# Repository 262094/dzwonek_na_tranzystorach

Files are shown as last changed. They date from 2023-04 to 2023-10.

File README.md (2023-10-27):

# dzwonek_na_tranzystorach
jest to aplikacja dzwonka z lat '80 typu słowik ze standardowego montażu przewlekanego THT, dzwonek został zaadaptowany na obecnie panujący trend miniaturyzacji elektroniki w połączeniu głownie montażu SMD z niektórymi elementami THT (tranzystor PNP BD140, brzęczyk bez generatora, kondensatory elektrolityczne 470uF, przycisk, złącze ARK500/2, potencjometr i kondensator ceramiczny 33nF), dzwonek udało się umieścić w wymiarach 66x37,5 (mm). W dzwonku występuje generator częstotliwości dla dzwonka złożony z przerzerzutnika Schmitta połączonego z układem Sziklaiego (wzmocnienie parametru B na wyjściu układu dla brzęczyka) oraz z przerzutnika monostabilnego jako modulatora generowanego tonu z poprzedniego przerzutnika. Układ może pracować w zasilaniu 9V DC jak i 230V AC po uprzednim zaadoptowaniu. Projekt został przygotowany do samodzielnego wytrawienia na laminacie pokrytym warstwą miedzi.

*** WIECEJ MOICH PROJEKTOW JEST DOSTEPNYCH NA MOIM KONCIE ZAPRASZAM DO ZAPOZANANIA SIE Z NIMI APLIKACJA HEALTH_CHECK ORAZ FINANCIFY***

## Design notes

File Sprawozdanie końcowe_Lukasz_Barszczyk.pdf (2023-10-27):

## Sprawozdanie końcowe

## Laboratorium Otwarte

## Dzwonek do drzwi typu słowik

Łukasz Barszczyk

Nr indeksu: 262094

Spis treści

### 1. Wstęp

Projekt obejmuje wykonanie dzwonka do drzwi typu słowik wykorzystując dwa

przerzutniki astabilne do generowania i modulowania tonu oraz wzmacniacz głośnikowy

w postaci dwóch tranzystorów (jeden NPN, drugi PNP) w układzie Sziklaiego

(układ wzmacniacza opartego | na | tranzystorach | bipolarnych o | dużym | wzmocnieniu,

rodzaj układu Darlingtona, w którym zastosowane są tranzystory o przeciwstawnej

(komplementarnej) polaryzacji). W celu dostosowania częstotliwości dźwięku do swoich

potrzeb mamy możliwość jej regulacji za pomocą potencjometru umieszczonego w układzie.

Typowe zastosowanie układu to dołączenie do urządzenia zasilania bateryjnego (np. baterii

9V) lub na co pozwala układ transformatora dzwonkowego. W drugim przypadku należy

pamiętać, że w takim systemie występuje napięcie sieci 230V i należy zachować szczególną

ostrożność.

Ideę działania układu zaczerpnięto z książki „Dla domu: 24 proste układy elektroniczne do

samodzielnego wykonania” autorstwa Marii i Wojciecha Nowakowskich. Na podstawie

zmodyfikowanego układu wykonano symulację w programie LTspice.

Ze względu na trudności w znalezieniu źródeł literaturowych opisujących działanie obwodu

zbliżonego do analizowanego, podstawowym źródłem wiedzy na temat sposobu działania było

badanie układu przez jego symulacje, pobudzanie zmianami parametrów oraz budowę układu

na płytce obwodu drukowanego i jego pomiary za pomocą oscyloskopu. Pomimo wielu różnic,

względem oryginalnego dzwonka, pomocne w zrozumieniu układu okazały się informacje

zamieszczone w Internecie na temat multiwibratorów.

### 2. Schemat układu i sposób działania

Na rys. 1. przedstawiono schemat ideowy układu.

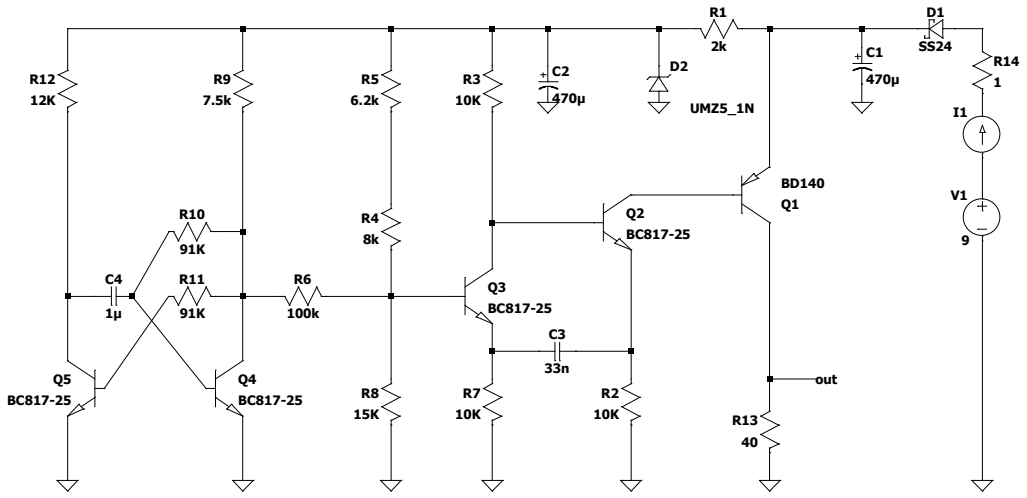
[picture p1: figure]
UMZ5_1N 470µ; out

Prezentowany układ jest współczesną wersją układu dzwonka do drzwi o przyjemnym

brzmieniu, którego pierwowzór został zbudowany z elementów przewlekanych w latach 80. ubiegłego wieku. Ówcześnie zbudowany był z elementów przewlekanych, które obecnie

zostały zastąpione elementami elektronicznymi wykonanymi w technologii montażu

powierzchniowego SMD. Dzięki temu urządzenie jest mniejsze, tańsze oraz łatwiejsze

w montażu.

Sposób działania układu polega na pracy tranzystorów Q2 oraz Q3, które tworzą

przerzutnik astabilny pracujący jako generator tonu. Częstotliwość generowanego tonu

możemy regulować za pomocą potencjometru (w symulacji LTspice potencjometr został

zastąpiony rezystorem). Tranzystory bipolarne Q4 oraz Q5 także pracują w konfiguracji

przerzutnika astabilnego. Zadaniem tego przerzutnika jest modulacja wysokości tonu

generowanego przez układ zbudowany z tranzystorów Q2 i Q3. Funkcję głośnikowego

wzmacniacza mocy pełni zewnętrzny tranzystor bipolarny Q1 – BD140.

Rys. 1. Schemat układu dzwonka

W symulacji na wejściu układu znajduję się źródło napięciowe sterowane prądem. Ten

element układu jest odpowiedzialny za symulowanie wciskania przycisku przez użytkownika

dzwonka, w celu odzwierciedlenia rzeczywistego obwodu (w schemacie właściwym, element ten został zastąpiony przyciskiem). Źródło napięciowe jest zależne od źródła prądowego

Tranzystory Q4 i Q5 tworzą multiwibrator dwustanowy monostabilny – układ jest

symetryczny lewa i prawa strona są bardzo podobne. Zakładamy, że po włączeniu napięcia

jeden z tranzystorów zostanie włączony, czyli na jego bazie pojawi się napięcie ok 0.7 V.

W teorii układ może pozostać w równowadze, jeżeli wartości jego elementów byłyby idealne

(takie same). W praktyce jednak tak nie jest więc układ przeskoczy do jednego ze skrajnych

stanów. Tranzystor Q5 w tym przypadku przewodzi, a Q4 jest zatkany, ponieważ występuje

ujemne napięcie w punkcie pomiędzy C4 a Q4. Ujemne napięcie bierze się stąd, że lewa

okładka kondensatora została zwarta do masy poprzez złącze C-E tranzystora Q5, była

na potencjale dodatnim, a prawa strona kondensatora na potencjale masy, jeśli kondensator

rozładował się poprzez Q5 to w punkcie pomiędzy C4 a Q4 wystąpiło napięcie ujemne,

ponieważ potencjał kondensatora obniżył się. Z tego względu Q4 jest zatkany. Jednak potencjał

cały czas rośnie, ponieważ kondensator coraz bardziej się rozładowuje. Kiedy napięcie bazy

tranzystora Q4 osiągnie ok. 0,7V to tranzystor Q4 się otworzy spowoduje to spadek napięcia

na bazie Q5 i jego zatkanie. Po naładowaniu się kondensatora C4, układ jest gotowy do

następnego wyzwolenia. Zadaniem tego przerzutnika jest modulacja wysokości tonu

generowanego przez układ zbudowany z tranzystorów Q2 i Q3.

Tranzystory Q2 i Q3 pracują w układzie przerzutnika Schmitta. Układem Schmitta

nazywamy układ, w którym oba stopnie są połączone gałęzie, w której występuje sumowanie

sygnałów pochodzących z obu stopni. Przerzutnik Schmitta ma w obwodzie wejściowym dwa

progi przełączania, przy których wyjście zmienia stan na przeciwny. Osiągnięcie przez napięcie

wejściowe określonego progu zależy od kierunku zmiany tego napięcia. Dla napięcia

narastającego obowiązuje próg górny, dla opadającego - dolny. Odległość między progami

określa się mianem szerokości pętli histerezy. Po przekroczeniu pewnego progu przerzutnik

przerzuca się na stan wysoki na wyjściu. Jeśli napięcie spadnie poniżej tego progu na wyjściu

układu pojawi się stan niski. Wpływ na stan niski w układzie wywiera umieszczony

kondensator emiterowy, który przemiennie ładuję się i rozładowuje. Na wyjściu układu

znajduję się tranzystor PNP (Q1), umożliwia on lepszą oscylację sygnału pomiędzy stanem

niskim, a wysokim, ponieważ do jego otwarcia na bazie wymagane jest napięcie o około 0,6V

niższe od napięcia kolektora, a dodatkowo wzmacnia sygnał. Jest to najprostszy generator

częstotliwości. Sprężenie zwrotne ujemne stabilizuje punkt pracy, a ponadto może nie dopuszczać do wystąpienia przesterowania w układzie. Układ pracuje wówczas bez

wchodzenia w obszar nasycenia, dzięki czemu uzyskuje się przebiegi o stromych zboczach

z małym opóźnieniem czasowym (zwanym histerezą) względem impulsów wyzwalających.

Układy Schmitta stosuje się jako przerzutniki monostabilne lub bistabilne oraz do formowania

przebiegów prostokątnych. Zaletą układu jest m.in to, że wejście układu nie jest objęte pętla

sprężenia zwrotnego i dzięki temu na wejściu nie istnieją sygnały wytworzone wewnątrz

układu, jak to występuje w układzie Ecclesa-Jordana. Ponadto wyjście układu jest dobrze

odseparowane od wejścia. W tym układzie sygnał wejściowy jest podawany na bazę

pierwszego tranzystora, a wyjście odczytuje się z kolektora drugiego tranzystora. W stanie

początkowym, kiedy sygnał wejściowy jest na poziomie niskim, oba tranzystory są wyłączone,

kondensator jest rozładowany poprzez oporniki bazy i kolektora.

Gdy sygnał wejściowy przekracza poziom progowy, napięcie na bazie pierwszego tranzystora

zaczyna rosnąć, co powoduje, że ten tranzystor zaczyna przewodzić. Wskutek tego kondensator

zaczyna się ładować poprzez tranzystor pierwszy i opornik bazy tranzystora drugiego. Gdy

napięcie na emiterze pierwszego tranzystora osiągnie poziom progowy, napięcie na bazie

drugiego tranzystora zaczyna rosnąć, co powoduje, że ten tranzystor także zaczyna przewodzić.

Teraz kondensator zaczyna się rozładowywać. Gdy napięcie na emiterze drugiego tranzystora

spadnie poniżej poziomu progowego, tranzystor ten przestaje przewodzić, a kondensator

zaczyna się ponownie ładować poprzez drugi tranzystor. W ten sposób przerzutnik Schmitta

z dwóch tranzystorów NPN ze wspólnym kondensatorem emiterowym umożliwia zmianę stanu

sygnału wejściowego między stanem niskim a wysokim w sposób stabilny i jednoznaczny,

niezależnie od szumów i zakłóceń w sygnale generując sygnał wyjściowy.

Tranzystory Q1 i Q2 pracują jako układ Sziklaiego układ wzmacniacza oparty

na tranzystorach bipolarnych o dużym wzmocnieniu, rodzaj układu Darlingtona, w którym

zastosowane są tranzystory o przeciwstawnej (komplementarnej) polaryzacji, tzn. np. pierwszy

z nich (na rysunku oznaczony Q2) jest n-p-n, a drugi p-n-p. Emiter pierwszego tranzystora

połączony jest z kolektorem drugiego, natomiast kolektor pierwszego tranzystora steruje wprost

bazą drugiego. Całość w układzie jak na rysunku obok zachowuje się jak pojedynczy tranzystor

n-p-n o dużym wzmocnieniu. Wynikowy tranzystor Sziklaiego swój kolektor ma tam, gdzie

jest emiter tranzystora Q1.

Układ prostownika z diodą (D1) i kondensatorem(C1) pozwala na zmianę napięcia

przemiennego na stałe napięcie pulsujące (zasilanie 230V). W przypadku zasilania z baterii 9V,

może to pomóc w uzyskaniu wyższych wartości napięcia, co jest przydatne w niektórych

układach elektronicznych. Jednakże, należy pamiętać, że napięcie wyjściowe takiego prostownika jest pulsujące i nie jest idealnie stabilne. Zastosowanie stabilizatora napięcia może

być konieczne, aby uzyskać stałe napięcie wyjściowe.

Układ stabilizatora (R1, D2, C2) pozwala na utrzymanie stałego napięcia wyjściowego

bez względu na zmiany napięcia zasilania i obciążenia. W przypadku braku stabilizatora,

napięcie wyjściowe będzie zmieniać się w zależności od stanu naładowania baterii, co może

wpłynąć na działanie urządzenia, które jest zasilane tymi bateriami. Zastosowanie stabilizatora

pozwala na uzyskanie stabilnego napięcia wyjściowego, co zwiększa nie tylko niezawodność

i trwałość urządzenia, ale także może pomóc w poprawie jakości działania

### 2.1 Modyfikacje schematu

Schemat z rysunku 1. po wstępnym przetestowaniu działa poprawnie i zgodnie

z założeniami postawionymi we wstępie. Jednak w celu wyeliminowania konieczności

zamawiania nowych elementów dokonano zamiany diody Zenera UMZ5_1N na diodę

o zbliżonych parametrach do tej BZV55C5V6. Zmiana ta nie wpływa znacząco na działanie

układu, gdzie jest dalej zachowane ustabilizowane napięcie, które nie spowoduje uszkodzenia

tranzystora Q4 napięciem wstecznym E-B (deklarowana wartość przez producenta

maksymalnego napięcia wstecznego 5V).

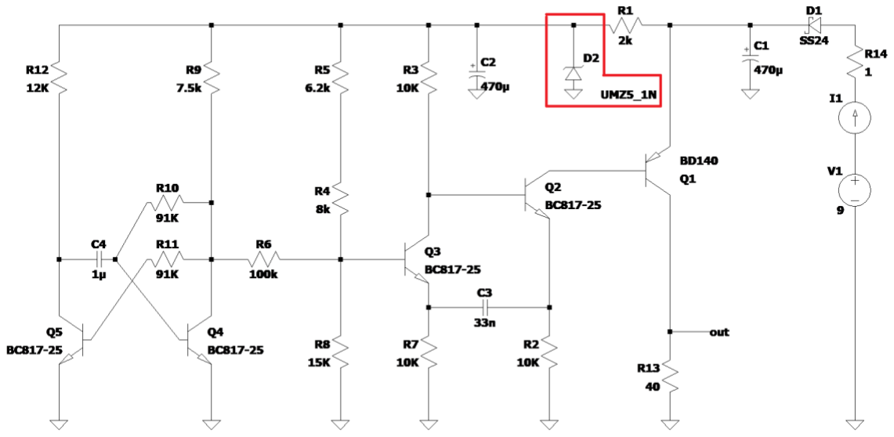
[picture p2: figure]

Rys. 2. Układ z zaznaczonym elementem, który wymieniono

### 3. Symulacja układu w programie LTspice

Ze względu na braki niektórych z elementów w LTspice, na których planowano wykonanie

układu przyjęto pewne uproszczenia w symulacji: zamiast diody Zenera BZV55C5V6

zastosowane w symulacji diodę UMZ5_1N oraz zamiast przycisku zastosowano źródło

napięciowe sterowane źródłem prądowym imitując tym pracę przycisku. Dla możliwości

usłyszenia dźwięku dzwonka w symulacji, zastosowano formułę „wave”, która generuje plik

dźwiękowy z programu według uzyskanych parametrów na wyjściu „out”. Przed wyjściem

układu umieszczono także rezystor o wartości 40 Ohm, służący za przybliżenie oporu

brzęczyka na wyjściu.

Rys. 3. Schemat ideowy układu w programie LTspice

W trakcie symulacji poddano analizie następujące parametry:

- Napięcie baza-emiter tranzystora Q2, Q3, Q4 oraz Q5
- Napięcie kolektora tranzystora Q4 oraz Q5
- Napięcia emitera tranzystora Q3 oraz Q2
- Napięcie uzyskane na wyjściu układu
- Napięcie uzyskane po wyprostowaniu przez prostownik

Biorąc pod uwagę właściwości aplikacyjne układu, za najważniejsze zostały uznane

napięcia uzyskane podczas pracy obu przerzutników. Szczegółowa analiza dokonywana jest

dla napięcia bateryjnego 9V – założono, że takie napięcie będzie najczęściej wykorzystywane.

### 3.1 Wykresy związane z pracą tranzystorów Q4 i Q5

Rysunki 4., 5., 6. i 7. ukazują przebiegi zgodne z oczekiwanymi. Podczas krótkich

impulsów włączających naprzemiennie tranzystory Q4 i Q5. Pracując w konfiguracji

przerzutnika astabilnego modulują wysokości tonu generowanego przez układ zbudowany

z tranzystorów Q2 i Q3.

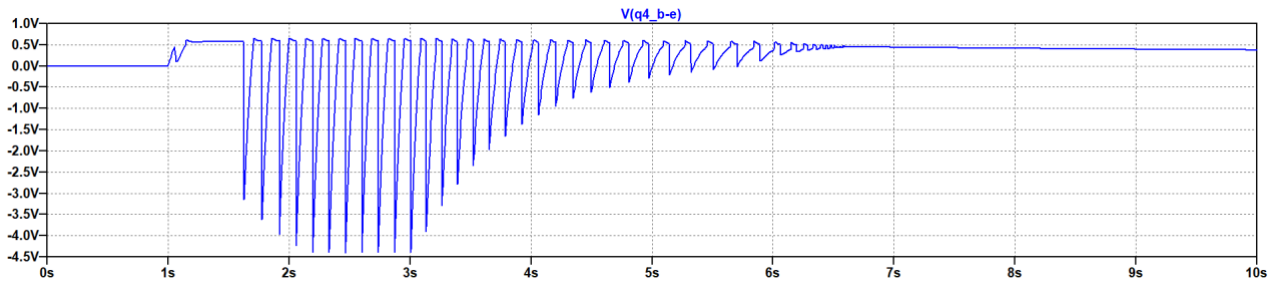
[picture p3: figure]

Rys. 4. Przebieg napięcia baza-emiter tranzystora Q4

Jak widać na rysunku powyżej (Rys. 4.) napięcie w symulacji nie przekracza wartości

deklarowanej przez producenta tranzystora dla napięcia wstecznego emiter-baza. Dzięki czemu

tranzystor nie przekracza deklarowanej wartości 5V i nie ulegnie uszkodzeniu w wyniku

przekroczenia tej wartości.

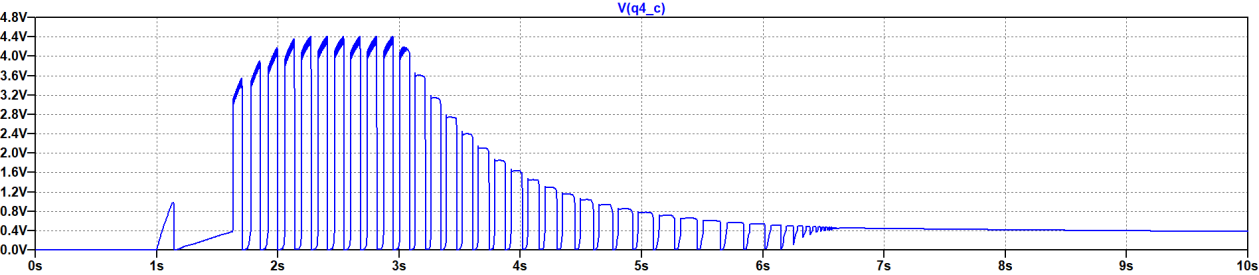
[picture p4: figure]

Rys. 5. Napięcie kolektora tranzystora Q4

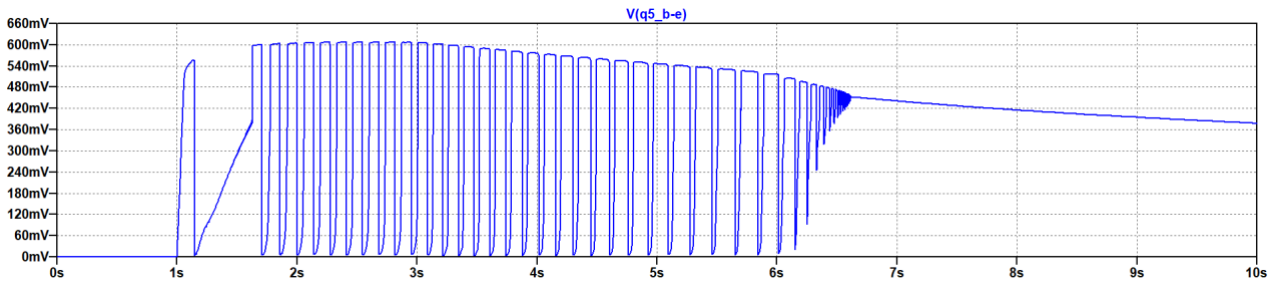
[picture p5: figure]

Rys. 6. Przebieg napięcia baza-emiter tranzystora Q5

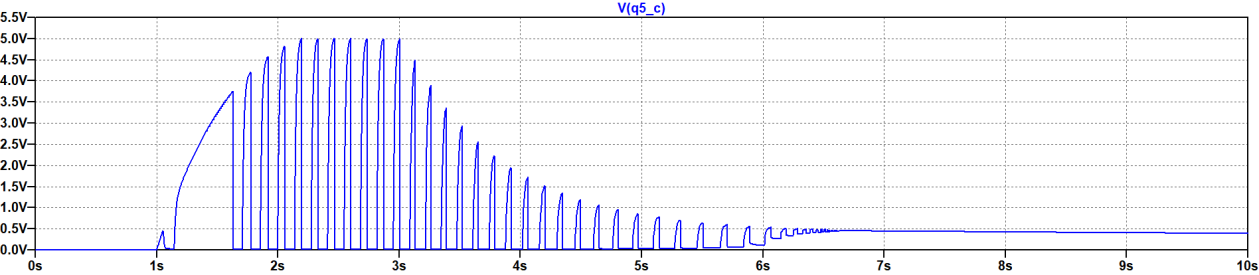
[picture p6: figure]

Rys. 7. Napięcie kolektora tranzystora Q5

### 3.2 Wykresy związane z pracą tranzystorów Q2 i Q3

Rys. 8. Napięcie baza-emitera tranzystora Q2 oraz Q3

Wykres na rysunku 8 przedstawia charakterystykę napięcia baza-emiter (Vbe) dla

tranzystora Q2 oraz Q3. Zgodnie z oczekiwaniami tranzystory te pracują tworzą przerzutnik

astabilny pracujący jako generator tonu w przedstawionym układzie. Wpływ na charakterystyki

wywiera rezystor umieszczony w układzie zmieniając jego wartości, charakterystyki ulegną

zmianą, a tym samym częstotliwość uzyskiwanego dźwięku.

### 3.3 Analiza dotycząca sygnału wyjściowego

Wykres na rysunku 9 i 10 przedstawia charakterystykę napięcia wyjścia układu

po wygenerowaniu i modulacji tonu. Na podstawie uzyskanej charakterystyki można

zauważyć, jak sygnał zmieniał się w czasie i wysokość jego napięcia. Maksymalna amplituda

wyjściowa uzyskanego przebiegu wynosiła 6V, a okres drgań w przybliżeniu wynosił 0,00042s.

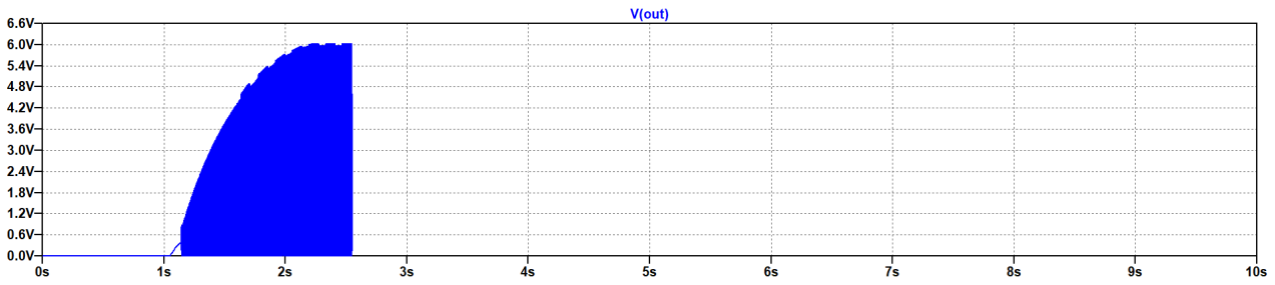
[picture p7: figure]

Rys. 9. Napięcie wyjściowe układu dzwonka

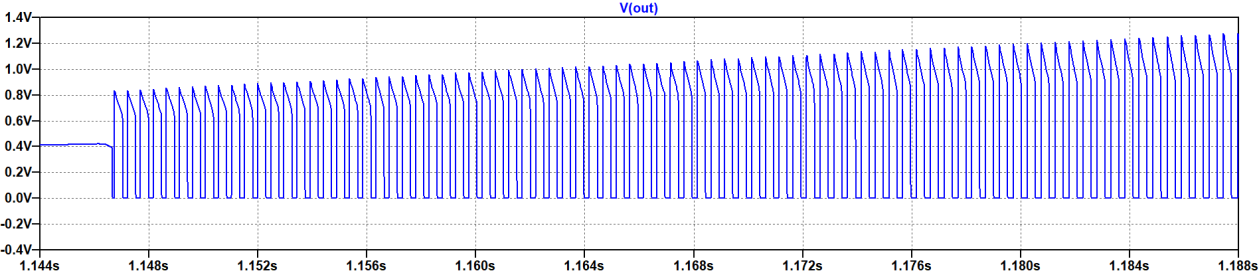
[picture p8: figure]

Rys. 10. Napięcie wyjściowe układu dzwonka w przybliżeniu

### 3.4 Analiza działania stabilizatora i prostownika

W układzie został zastosowany układ prostownika (Rys. 11.) oraz stabilizatora (Rys.

12.). Prostownik napięcia składający się z diody (D1) i kondensatora (C1) pozwala na zmianę

napięcia przemiennego na stałe napięcie pulsujące w przypadku zasilania układu napięciem

230V (należy pamiętać o transformatorze dzwonkowym!!!). Stabilizator (R1, D2, C2) pozwala

na utrzymanie stałego napięcia wyjściowego bez względu na zmiany napięcia zasilania

i obciążenia. W przypadku braku stabilizatora, napięcie wyjściowe będzie zmieniać się

w zależności od stanu naładowania baterii, co może wpłynąć na działanie urządzenia, które jest

zasilane tymi bateriami.

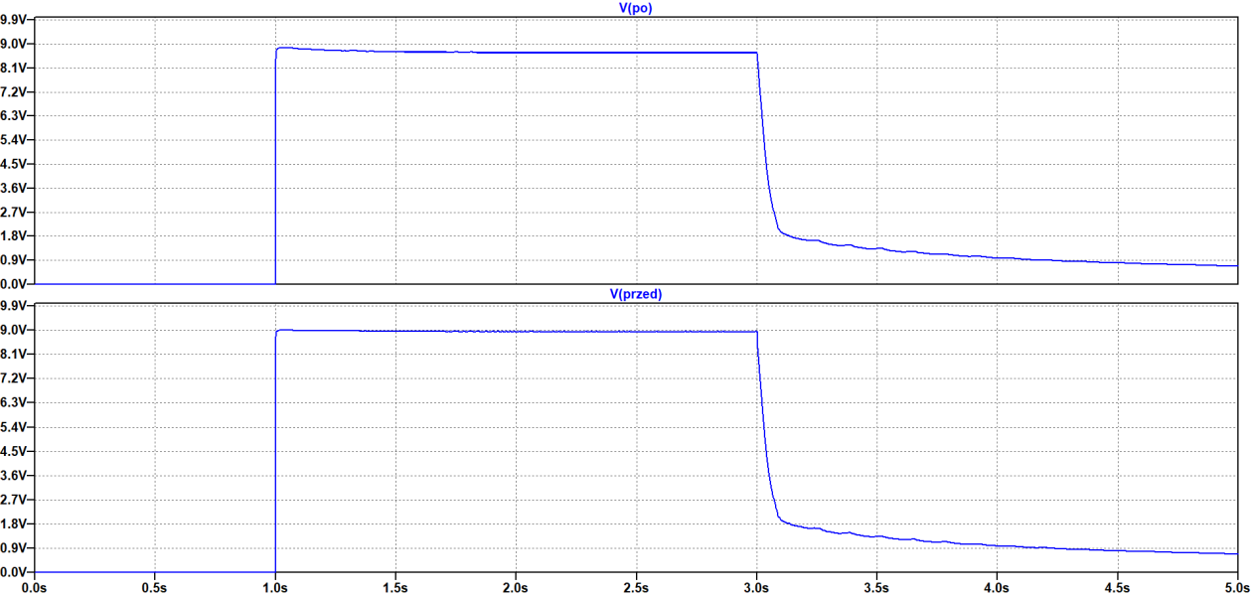
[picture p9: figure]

Rys. 11. Napięcie przed układem prostownika i po

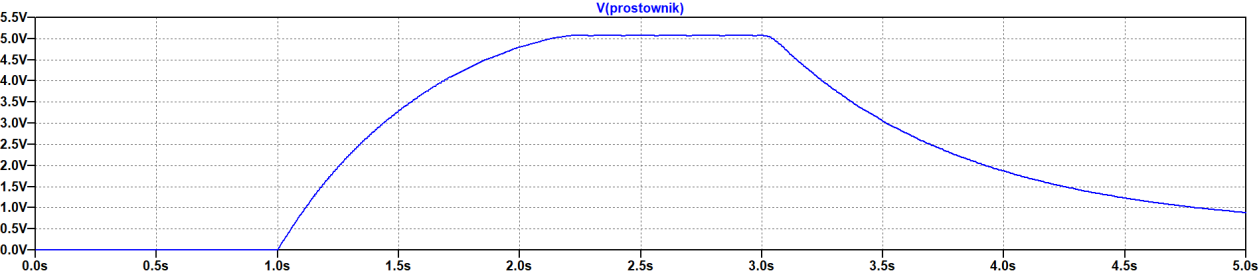
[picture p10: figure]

Rys. 12. Napięcie układu za stabilizatorem napięcia (Upp = 5V po ustabilizowaniu)

### 4. Projekt płytki drukowanej w Eagle

W celu zaprojektowania warstwy ścieżek oraz rozmieszczenia komponentów wykorzystano

program Eagle. W trakcie rysowania schematu podjęto decyzję o dodaniu złącza ARK w celu

umożliwienia łatwiejszego podłączenia układu. Schemat zaprojektowano zgodnie ze

schematem z rysunku 3.

Rys. 13. Schemat zaprojektowany w programie Eagle

Docelowy wymiar płytki to 66x37.5 mm, możliwe jest jednak zmniejszenie tego

wymiaru przez zmianę położenia komponentów. Jednak ostatecznie rozłożenie elementów

na płytce drukowanej okazało się optymalne i na tej podstawie zdecydowano, że zmniejszanie

wymiaru płytki nie jest konieczne.

Po wykonaniu płytki w celu pomiaru prądu na wejściu układu, do schematu dodano

rezystor wartości 39 Ω. W trakcie pracy układu zostanie na nim wykonany pomiar napięcia

oscyloskopem i zgodnie z przekształconym prawem Ohma wyznaczony zostanie prąd płynący

w układzie.

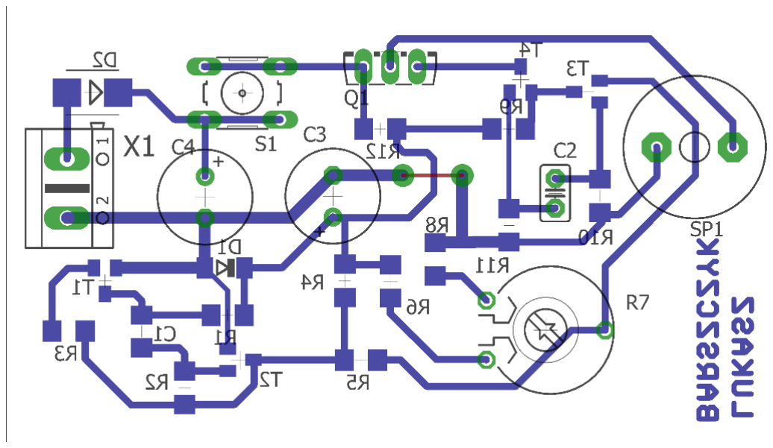
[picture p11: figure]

Rys. 14. Rozmieszczenie elementów na płytce PCB

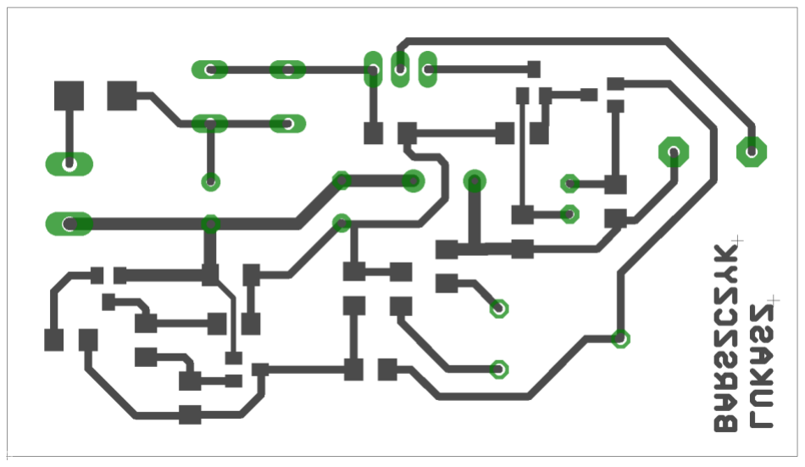
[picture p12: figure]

Rys. 15. Topologia połączeń

W trakcie projektowania schematu ścieżek starano się rozmieścić tak elementy, aby

zajęły jak najmniej miejsca na laminacie. Jednocześnie ze względu na niewielkie prądy

pobierane przez układ oraz zasilanie względnie niskim napięciem (typowo 9 V) rozmieszczenie

topologii nie wymagało rygorystycznego planowania odległości między ścieżkami ani ich

szerokości. Zastosowano się do podstawowych zasad zaimportowanych z dostarczanych

na stronie kursu pliku „OpenLab.dru”. Układ ścieżek i elementów poddawany był

modyfikacjom, do czasu aż sprawdzanie błędów DRC przestało wykazywać błędy dotyczące

układu. Po ostatecznym ułożeniu wszystkich komponentów jedynym zwracanym błędem były

przejścia ścieżek pod niektórymi elementami SMD. Ze względu na małe znaczenie na działanie

układu błędy zostały usunięte ręcznie.

### 4.1 Zestawienie wszystkich komponentów

W tabeli 1. przedstawiono zestawienie wszystkich elementów wykorzystanych do budowy

układu.

Nazwa | Typ | Wartość | Obudowa
Q1 | tranzystor | BD140 | SOT32
Q2 | tranzystor | BC817-25 | SOT23
Q3 | tranzystor | BC817-25 | SOT23
Q4 | tranzystor | BC817-25 | SOT23
Q5 | tranzystor | BC817-25 | SOT23
C1 | kondensator ceram. | 1μ | SMD-1206
C2 | kondensator ceram. | 33n | raster 2.54 mm
C3 | kondensator elektrolityczny | 470 μF | Ø 8x12 mm raster 3.5 mm
C4 | kondensator elektrolityczny | 470 μF | Ø 8x12 mm raster 3.5 mm
D1 | dioda Zenera | BZV55C5V6 | SOD80
R1 | rezystor | 12k | SMD-1206
R2 | rezystor | 91k | SMD-1206
R3 | rezystor | 91k | SMD-1206
R4 | rezystor | 7.5k | SMD-1206
R5 | rezystor | 100k | SMD-1206
R6 | rezystor | 6.2k | SMD-1206
R7 | potencjometr | PT10LV10 | PT10-leżąca
R8 | rezystor | 15k | SMD-1206
R9 | rezystor | 10k | SMD-1206
R10 | rezystor | 10k | SMD-1206
R11 | rezystor | 10k | SMD-1206
R12 | rezystor | 2k | SMD-1206
SP1 | brzęczyk | KC-1206 | AL60P
D2 | dioda Schottky'ego | SS24 | SMD-B
S1 | przycisk | | raster 6x6 mm
X1 | złącze | | ARK500/2

Tabela 1. Zestawienie wszystkich niezbędnych elementów

### 5. Wykonanie i pomiary

Topologia połączeń z rysunku 15. została wydrukowana przy użyciu drukarki laserowej

na papierze kredowym. Przygotowany laminat został docięty do wymiarów wydruków oraz

przetarty czyścikiem do laminatu, w celu usunięcia zanieczyszczeń laminat został wymyty

wodą oraz przepłukany alkoholem izopropylowym. Wzór naniesiono na jednostronny

laminat miedziany przy użyciu techniki termo transferu i trawienia w nadsiarczanie sodu.

Procedura wykonania wyglądała następująco:

- Przycięcie laminatu do żądanych wymiarów przy pomocy gilotyny.
- Wydruk ścieżek drukarką laserową na nośniku (papier kredowy).
- Czyszczenie powierzchni laminatu.
- Termo transfer ścieżek z nośnika na laminat.
- Kontrola jakości naniesionych ścieżek
- Trawienie w wodnym roztworze nadsiarczanu sodu.
- Kontrola procesu trawienia.
- Zdjęcie maski z laminatu, przy pomocy drucianej szczotki pod wodą.
- Kontrola ścieżek
- Wywiercenie otworów montażowych.

Po odklejeniu papieru i optycznej inspekcji ścieżek na płytce nie była wymagana żadna

korekcja z wykorzystaniem permanentnego pisaka. Zdecydowano o rozpoczęciu trawienia

płytki. Po wytrawieniu powierzchni miedzi niezasłoniętej tonerem i oczyszczeniu powierzchni

laminatu przystąpiono do inspekcji powstałych ścieżek. Po stwierdzeniu braku defektów

przystąpiono do wywiercenia otworów w celu umieszczenia w nich komponentów.

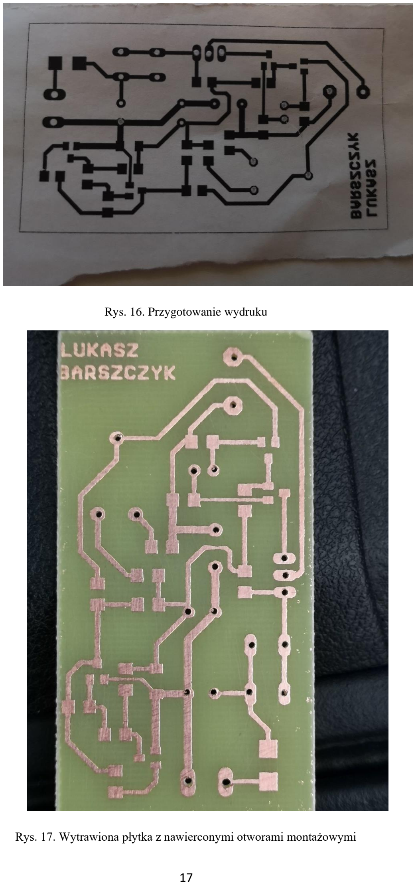
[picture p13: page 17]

Rys. 16. Przygotowanie wydruku

Rys. 17. Wytrawiona płytka z nawierconymi otworami montażowymi

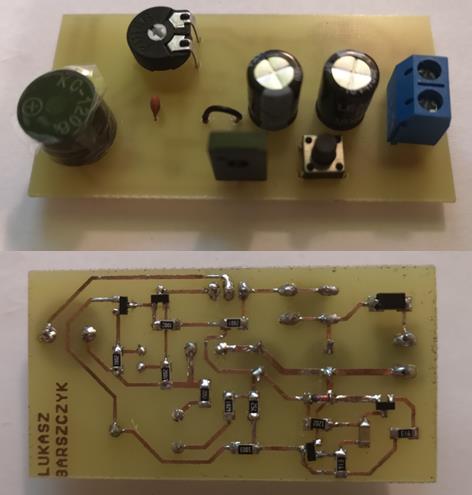
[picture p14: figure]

Rys. 18. Rozmieszczone i przylutowane komponenty do laminatu

### 5.1 Schematy pomiarowe

Schemat pomiarowy z rysunku 19. został wykorzystany do pomiaru wartości natężenia

prądu w układzie na podstawie tej wartości została wyznaczona moc pobierana przez układ

I=U/R, P=I*U.

Rys. 19. Pomiar natężenia prądu

Pomiar prądu na wejściu układu wykonano metodą techniczną. Do gałęzi zasilania

układu dołączono szeregowo rezystor pomiarowy 39 Ω i za pomocą oscyloskopu wykonano

pomiar spadku napięcia między jego wyprowadzeniami. Następnie zgodnie z przekształconym

prawem Ohma, na podstawie odczytanego napięcia i znanej w przybliżeniu rezystancji

wyznaczono prąd.

Schemat z rysunku 20. został wykorzystany do pomiaru wartości napięcia na wyjściu

układu, a tym samym do zaobserwowania przebiegu charakterystyki napięcia w czasie.

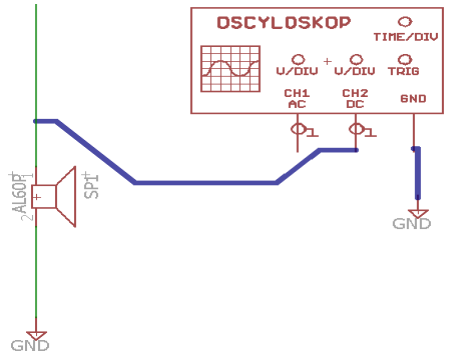
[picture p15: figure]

Rys. 20. Pomiar napięcia sygnału wyjściowego

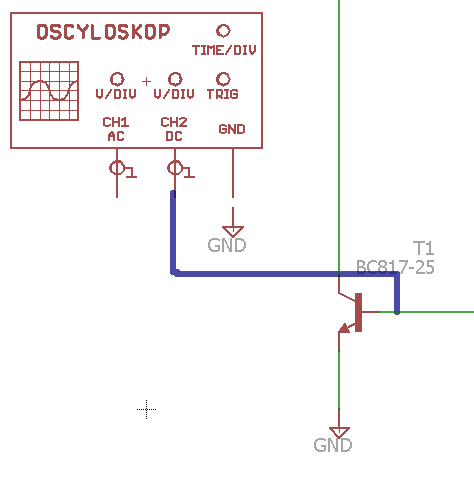
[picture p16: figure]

Rys. 21. Pomiar napięcia baza-emiter tranzystora T1

Ze względu na sposób działania układu, zdecydowano, że najistotniejszymi

parametrami do zarejestrowania będzie przebieg napięć baza-emiter na tranzystorach

umieszczonych w układzie. Te tranzystory odpowiadają za generowanie i modulowanie

częstotliwości uzyskiwanego przebiegu na wyjściu układu

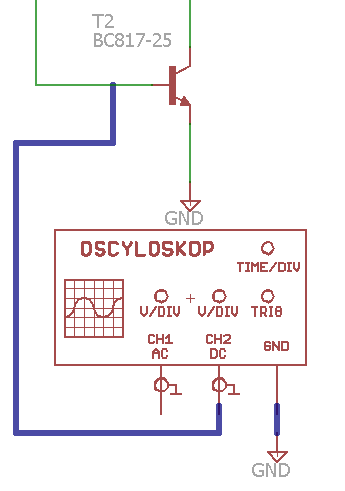
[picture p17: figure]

Rys. 22. Pomiar napięcia baza-emiter tranzystora T2

Na zamieszczonym rysunku 23. widać schemat do pomiaru napięcia za stabilizatorem

umieszczonym w układzie. Umieszczony stabilizator nie tylko stabilizuje napięcie w układzie,

ale również pozwala nie uszkodzić tranzystorów w wyniku napięcia wstecznego emiter-baza.

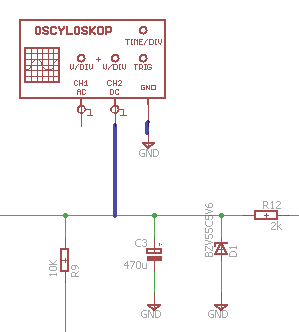
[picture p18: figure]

Rys. 23. Pomiar napięcia za stabilizatorem napięcia

Rys. 24. Pomiar napięcia za prostownikiem napięcia

### 5.2 Pomiary dotyczące pracy tranzystorów Q4 i Q5

Dokładne dobranie zakresów pomiarowych i podstawy czasu pozwoliło na precyzyjne

przedstawienie przebiegów napięć na złączach baza-emiter tranzystorów. Zebrane przebiegi

pokrywają się z uzyskanymi w symulacji. Uzyskane przebiegi zostały zebrane dla napięcia

zasilającego równego 9 V. Zbieżność przebiegów z symulacją świadczy o poprawnym

zaprojektowaniu, wykonaniu i działaniu układu.

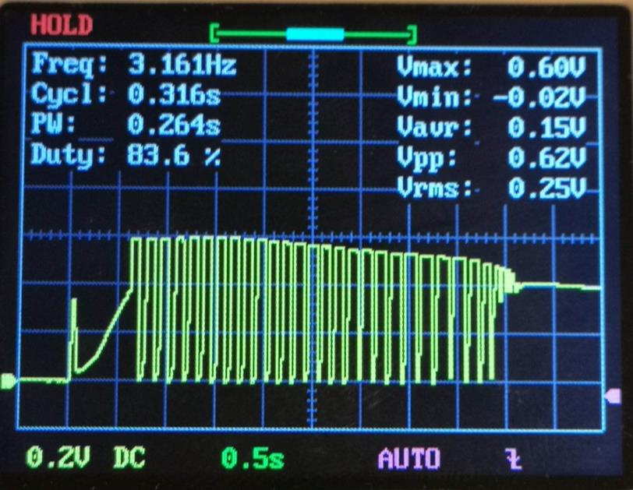
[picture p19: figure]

Rys. 25. Pomiar napięcia baza-emiter tranzystora T1

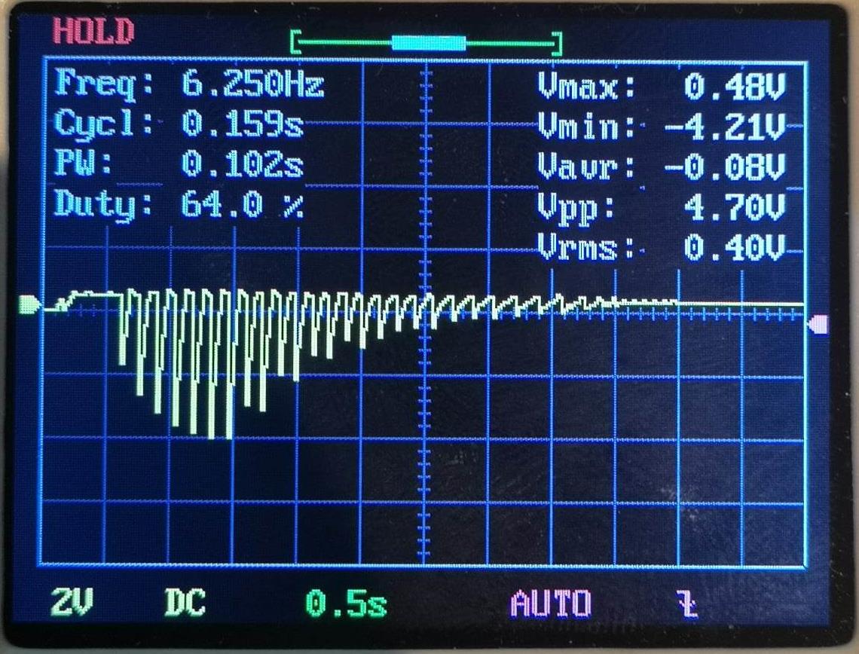
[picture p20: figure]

Rys. 26. Pomiar napięcia baza-emiter tranzystora T2

### 5.3 Pomiary dotyczące pracy stabilizatora i prostownika

Na rysunku 27. prostownika oraz 28. stabilizatora zostały przedstawione przebiegi

charakterystyk napięciowych.

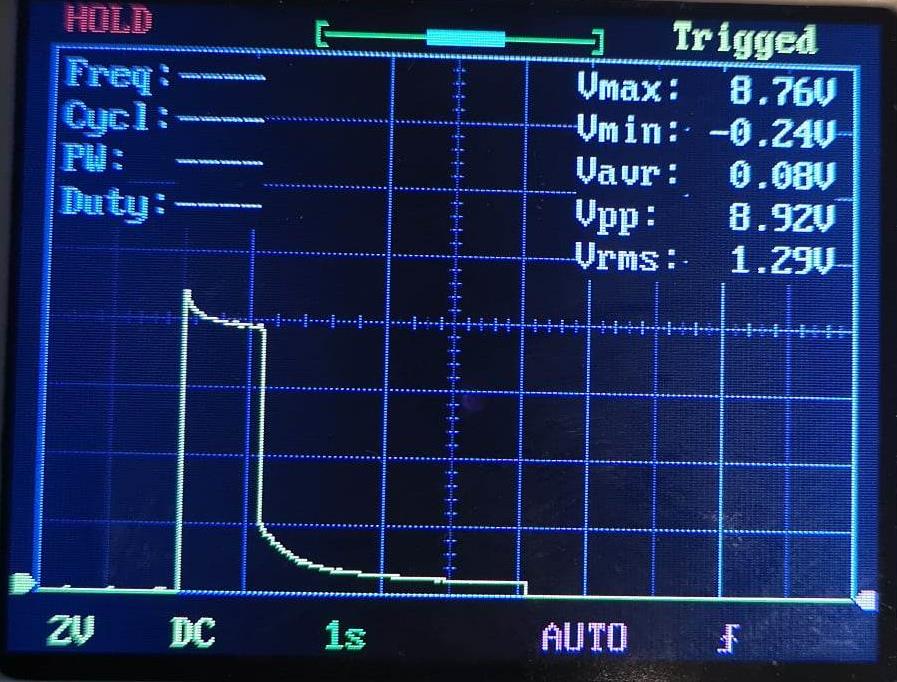
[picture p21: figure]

Rys. 27. Napięcie za układem prostownika

Prostownik napięcia składający się z diody (D1) i kondensatora (C1) pozwoli na zmianę

napięcia przemiennego na stałe napięcie pulsujące w przypadku zasilania układu napięciem

230V (należy pamiętać o transformatorze dzwonkowym!!!). Jak widać na zamieszczonym

rysunku 26. przebieg charakterystyki pokrywa się z symulacją programu LTspice.

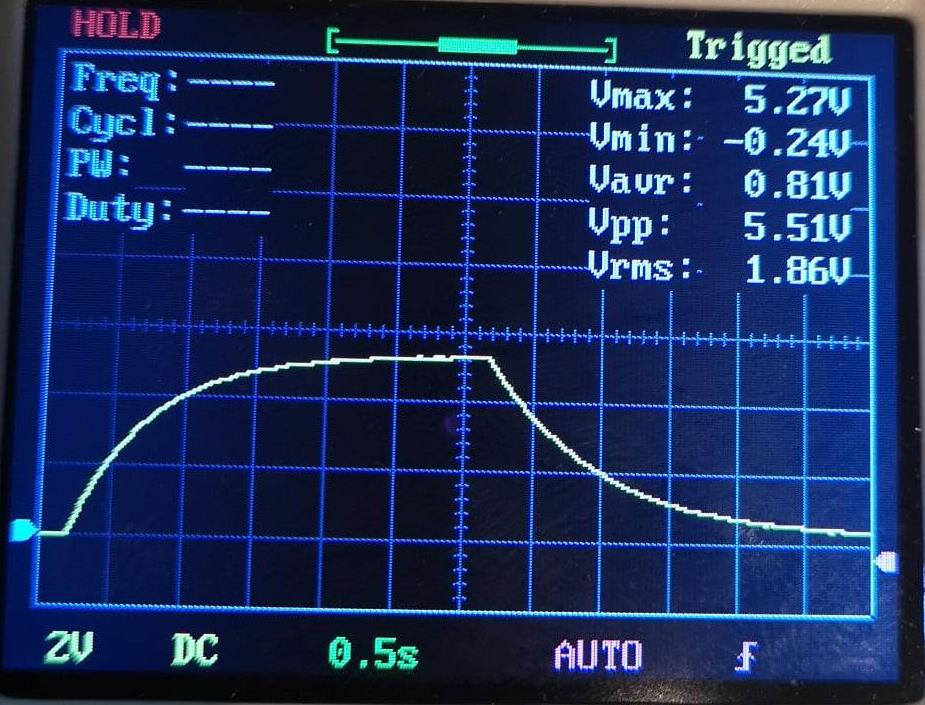
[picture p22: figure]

Rys. 28. Napięcie za układem stabilizatora

Stabilizator (R1, D2, C2) pozwolił na utrzymanie stałego napięcia wyjściowego bez

względu na zmiany napięcia zasilania i obciążenia. Zastosowanie diody Zenera

BZV55C5V6 pozwoliło w układzie na obniżenie napięcia. Ten zabieg zapobiegnie

uszkodzeniu tranzystora T2 w przypadku napięcia wstecznego Emiter-Baza co widać

na rysunku 26. gdzie przedstawiono napięcie baza-emiter tranzystora. Deklarowana

wartość producenta dla takiego napięcia wynosi 5V. Jak widać uzyskana wartość

maksymalna wynosi 4.21V, więc nie dojdzie do uszkodzenia tranzystora w wyniku napięcia

wstecznego.

### 5.4 Pomiar prądu występującego w układzie

Do pomiaru prądu w układzie wykorzystany został dołączony na wejściu rezystor

pomiarowy o rezystancji wynoszącej 39 Ω. Na danym rezystorze został zanotowany spadek

napięcia, a następnie, zgodnie z przekształconym prawem Ohma został wyliczony prąd płynący

na wejściu układu oraz obliczona moc.

Rys. 29. Spadek napięcia na rezystorze 39 Ω w celu pomiaru prądu

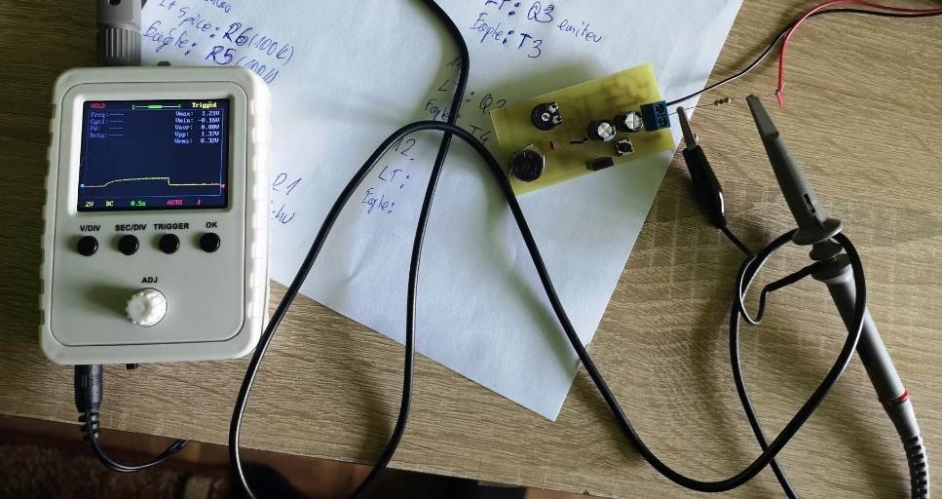
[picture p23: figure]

Rys. 30. Pomiar spadku napięcia na rezystorze 39 Ω

Jak widać na rysunku 29. uzyskana charakterystyka osiąga wartość maksymalną dla

1.21V, jest to spadek napięcia na rezystorze 39 Ω. Z przekształconego prawa Ohma zostało

obliczone natężenie prądu zasilającego układ:

I =

U
R

=

1,21V
39Ω

≈ 0,031A

Znając wartość natężenia prądu została wyznaczona moc układu:

P = U ∗ I = 9V ∗ 0,031A = 0,279W

Uzyskane wyniki są zgodne z oczekiwanymi i pokrywają się z symulacją.

### 5.5 Pomiary dotyczące sygnału wyjściowego

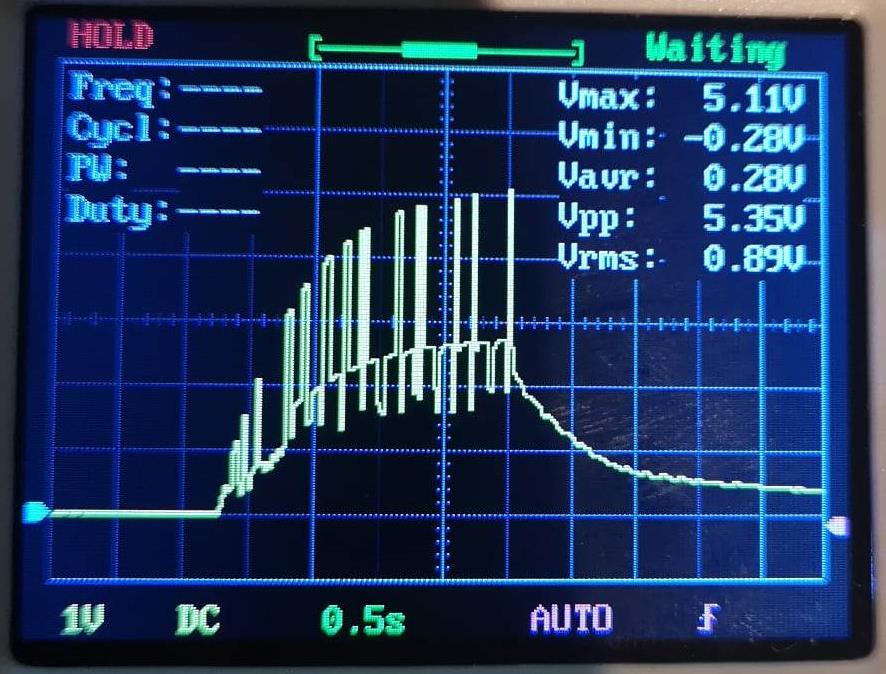
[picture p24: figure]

Rys.31. Napięcie wyjściowe układu dzwonka

Wykres na rysunku 31. przedstawia charakterystykę napięcia wyjściowego układu po

wygenerowaniu i modulacji tonu. Największa amplituda uzyskanego wyniku wynosi 5,11V.

Sygnał względem symulacji jest zbliżony, jednak trochę od niej odbiega. Powstają chwilowe

piki, które uzyskują wysokie, bądź niskie wartości. Najprawdopodobniej jest to związane

z niewłaściwą charakterystyką tranzystora lub też zakresem pracy brzęczyka 4-8V.

### 6. Wnioski

Wykonany układ dzwonka zaczerpnięty z książki [4], po modyfikacja i przystosowaniu

go do pracy na elementach SMD okazał się być w pełni funkcjonalny i może być

z powodzeniem stosowany w praktycznym zastosowaniu. Układ oprócz zasilania

bateryjnego 9V, można przystosować do pracy z zasilania napięciem przemiennym 230V

po wcześniejszym dodaniu transformatora dzwonkowego.

Wyliczone i symulacyjne parametry pracy dla zmodyfikowanego układu

w zadowalającym stopniu pokryły się z wartościami zmierzonymi. Odstępstwa

najprawdopodobniej wynikają z tolerancji stosowanych elementów, zarówno biernych jak

i czynnych.

Ujawnione w pomiarach zjawisko pojedynczych pików na wyjściu układu

najprawdopodobniej jest związane z niewłaściwą charakterystyką tranzystora. Aby poznać

dokładne przyczyny tego zjawiska i znaleźć możliwość jego wyeliminowania konieczne

są dalsze symulacje i prace prowadzące do jego modyfikacji.

Oświadczenie o samodzielności pracy

Oświadczam, że projekt został sprawdzony, jest kompletny i spełnia wymagania

projektowe. Oświadczam również, że został wykonany w pełni samodzielnie.

Literatura i źródła wiedzy

[1] https://www.youtube.com/watch?v=Ll-Jye7EP3g
[2] https://www.youtube.com/watch?v=GOGdxS45LCI
[3] https://pl.wikipedia.org/wiki/Multiwibrator
[4] Książka „Dla domu: 24 proste układy elektroniczne do samodzielnego wykonania” autorstwa Marii i Wojciecha Nowakowskich

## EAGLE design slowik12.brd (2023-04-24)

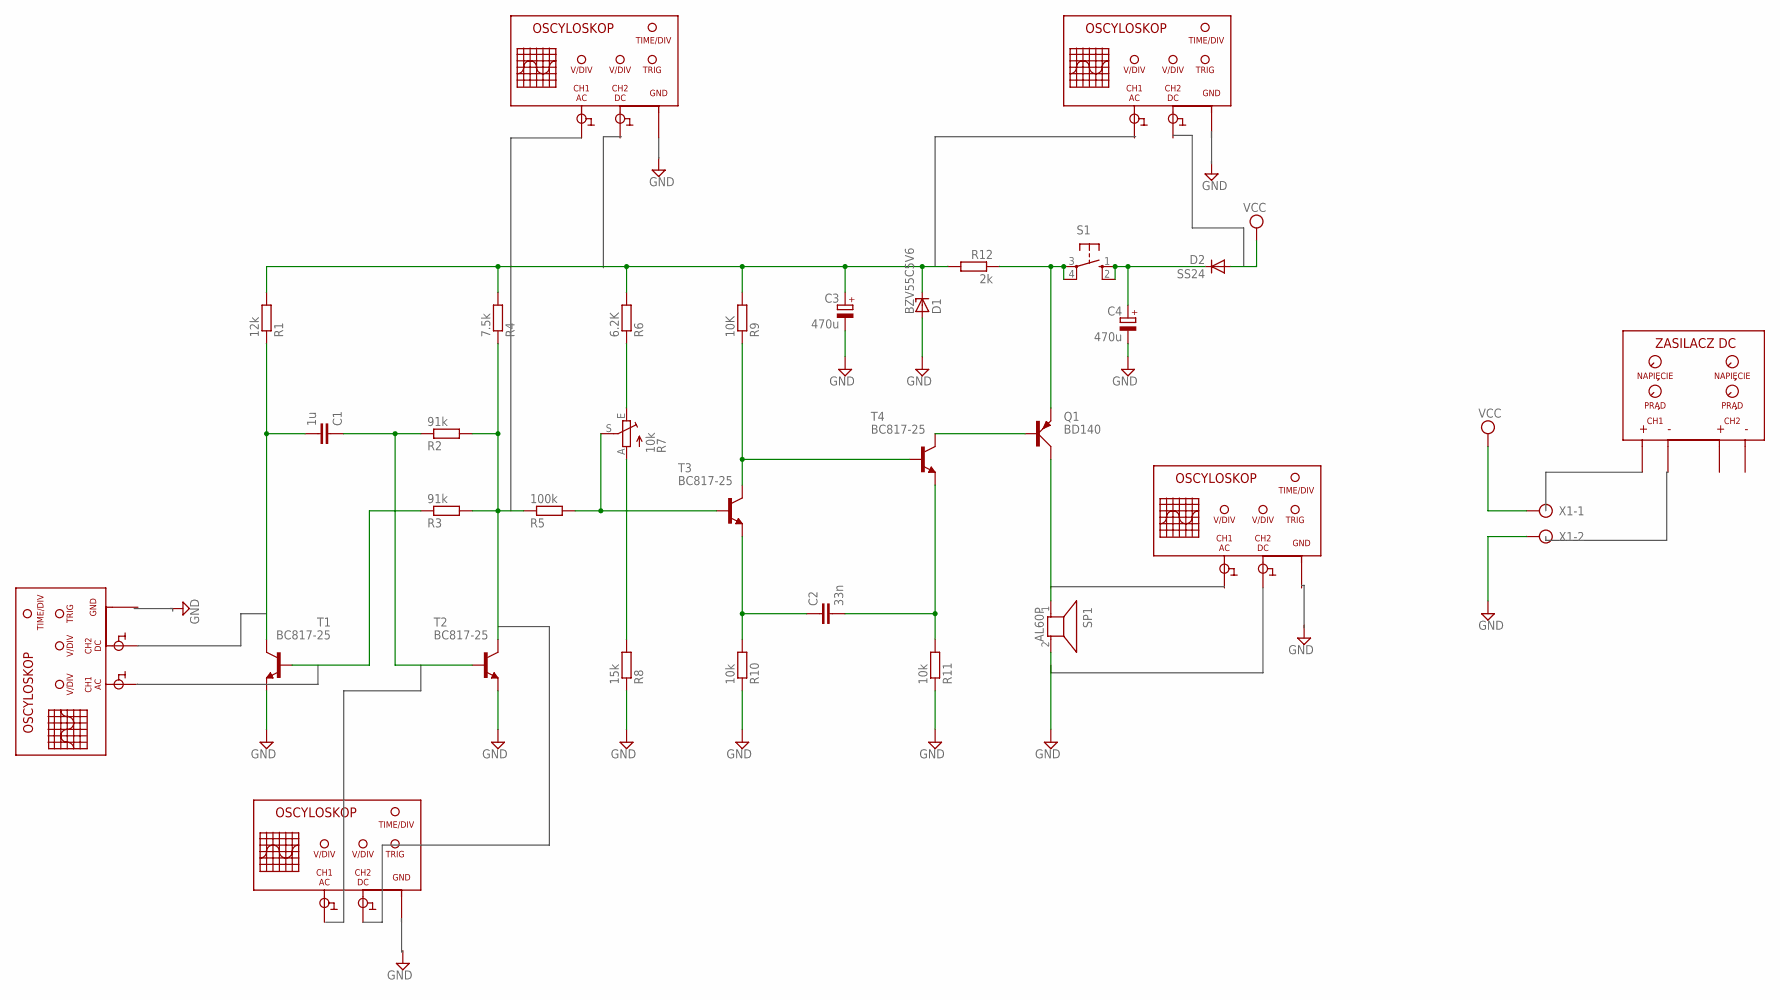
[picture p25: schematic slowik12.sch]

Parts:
C1: 1u; C1206
C2: 33n; C2.5-2
C3, C4: 470u; E3,5-8
D1: BZV55C5V6; SOD80C
D2: SS24; SMB
Q1: BD140; TO126AV
R1: 12k; R1206
R2, R3: 91k; R1206
R4: 7.5k; R1206
R5: 100k; R1206
R6: 6.2K; R1206
R7: 10k; PT-10
R8: 15k; R1206
R9: 10K; R1206
R10, R11: 10k; R1206
R12: 2k; R1206
S1: 10-XX; B3F-10XX
SP1: AL60P
T1, T2, T3, T4: BC817-25; SOT23-BEC
U$1, U$2, U$4, U$5, U$6: OSCYLOSKOP_DC_DC; OSCYLOSKOP
U$3: ZASILACZ
X1: AK500/2

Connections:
GND: C3.-, C4.-, D1.A, R8.1, R10.1, R11.1, SP1.2, T1.E, T2.E, X1.2
unnamed: R6.1, R7.E
unnamed: R7.A, R8.2
unnamed: Q1.E, R12.1, S1.3, S1.4 (P1)
unnamed: Q1.C, SP1.1
unnamed: Q1.B, T4.C
unnamed: C2.2, R11.2, T4.E
unnamed: C4.+, D2.C, S1.1 (S), S1.2 (S1)
unnamed: R9.1, T3.C, T4.B
unnamed: C2.1, R10.2, T3.E
unnamed: C1.2, R1.1, T1.C
unnamed: R2.2, R3.2, R4.1, R5.1, T2.C
unnamed: C1.1, R2.1, T2.B
unnamed: R3.1, T1.B
unnamed: R5.2, R7.S, T3.B
unnamed: C3.+, D1.C, R1.2, R4.2, R6.2, R9.2, R12.2
VCC: D2.A, X1.1

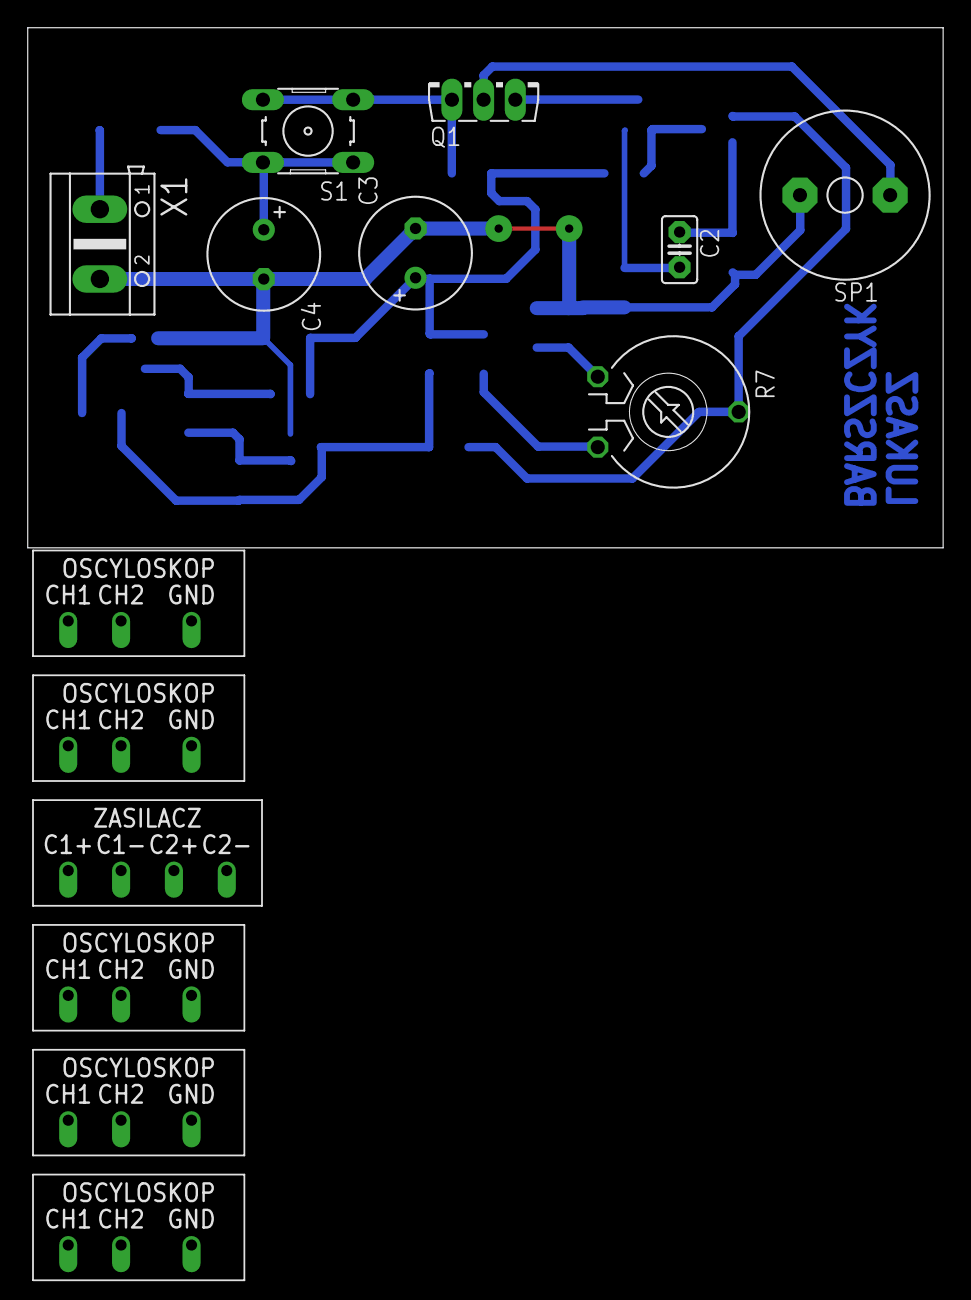
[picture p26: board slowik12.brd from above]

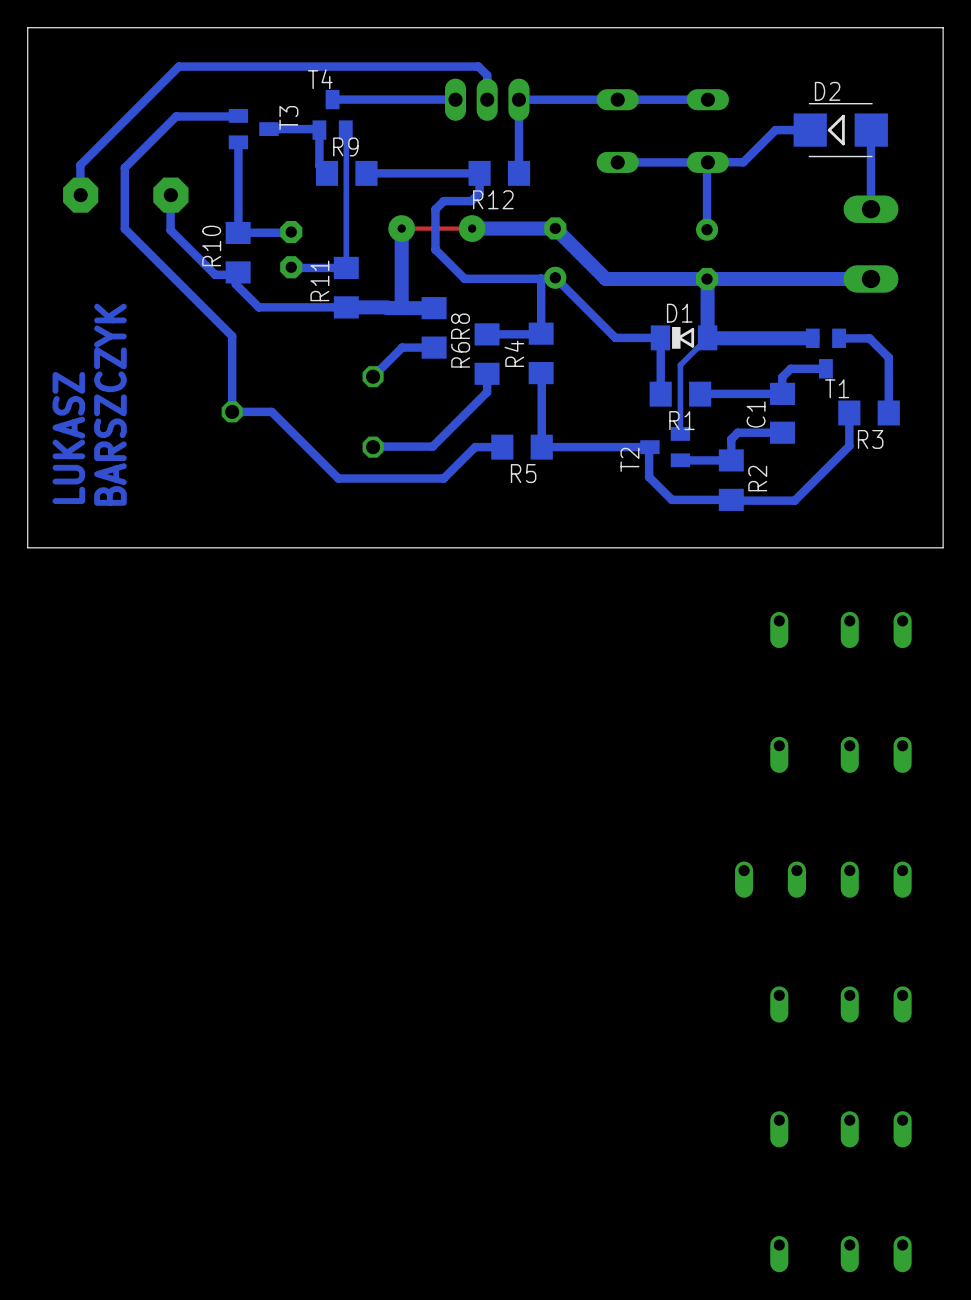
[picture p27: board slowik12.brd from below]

Board: 2 copper layers, 66.0 x 37.5 mm, 32 parts (18 on the bottom side), 17 nets.
